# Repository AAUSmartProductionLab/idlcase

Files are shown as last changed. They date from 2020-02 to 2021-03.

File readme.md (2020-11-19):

## Overview

This repository contains everything related to the Industrial data logger suitcase, including Raspberry Pi configuration in `ansible/`, firmware for actual devices (`espBME280/`, `espButton` ... ) and `dash/` which glues a lot of stuff together.

## Concept drawing
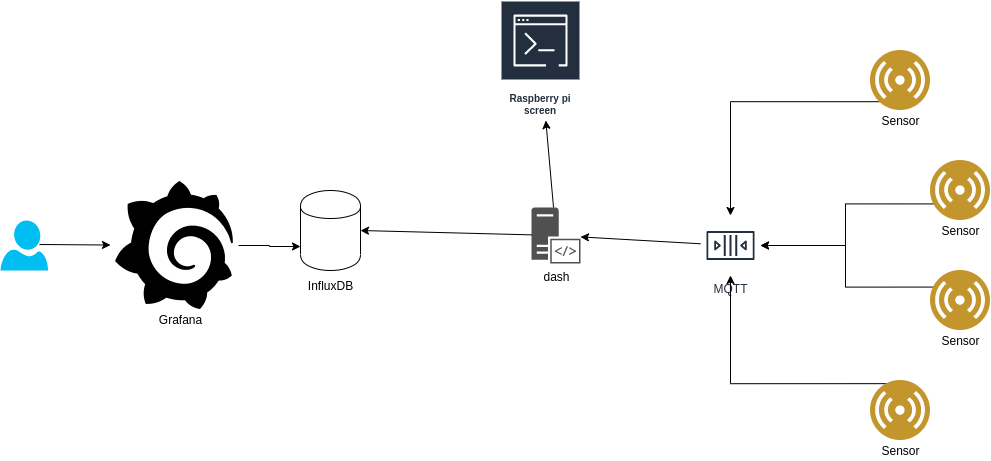
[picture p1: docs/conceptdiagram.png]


Data flows from sensors, though MQTT where `dash` listens for events which it then passes on to the GUI of the Raspberry Pi and stores it in the database.
 
Users access a Grafana frontend where they will be able to browse time series data directly from the database.
All the above software runs locally on the Raspberry Pi

## Connectivity
Raspberry Pi(s) continuously tries to join a VPN with our cloud server - the cloud server acts as a reverse proxy and passes HTTP requests for configured domains directly to the Raspberry Pis inside the VPN. Traffic not inside the VPN and also not directly connected to the Pi's wifi network will be rejected.

## Firmware over-the-air updates
The OTA scheme implemented tries to solve two scenarios
* A developer sits in platformio and wants to update all BME280 sensor devices
* A case is pulled out - some BME280 sensors are updated, some are not - those that are not should be able to update themselves without anyone touching the IDE

To solve these scenarios, the `dash/` projects host simple JSON files describing the latest version of a given firmware type - When a device cold boots, it will try to compare its release to the one fetched from `dash`.

When a developer wants to upload new firmware, `idlversion` and `idluploader` helps figuring out what version number to use next, when running "Upload" it will upload the firmware to the IDL case and publish a message on MQTT which devices listen to. Devices then to the regular OTA update just as if hey where cold booted.

## WifiManager
Our Library IDLNetworking makes use of [tzapu's wifimanager](https://github.com/tzapu/WiFiManager/tree/development). If the ESP device cannot connect to a known wifi it will start the wifimanager. The device will create a hotspot named "CONFIGURE ME - 12AB34" with the ending being the device ID. When connecting to this hotspot all traffic will be routed to a configuration portal that can be accecced with any browser. Connecting from an Android device this portal pops up by itself via a notification. Is that not the case the portal can be accessed on ip address `192.168.1.4`. 
From the portal it is possible to select any nearby access point and type in the password for it. As well as selecting access point it is also possible to set the MQTT server and port to publish on. Finally you can set the server where the ESP-device will check for firmware updates.
Writing `true` into the field named "use defaults below" will set MQTT and firmware server to the ip of gateway.
The protal is kept open for 5 minutes before the device tries to connect to known wifi again.  
Known bugs: wifimanager opens the configuration portal on every other reset. See issue [#1067](https://github.com/tzapu/WiFiManager/issues/1067) for updates. 

## BOM
Raspberry Pi
Raspberry Pi display
4G GSM dongle
esp32 devices and sensors

## MQTT namespaces and Datatypes
Two high-level namespaces exist at the moment, `idl` and `idlota`

### /idl/<deviceID>/<messageType>
Used for incoming events and metrics, `dash` assumes data is metric by default. `<deviceID>`, is used to tag the data and `<messageType` is dictating the format of the json payload. Two message-type formats exists, `events` and `measurements`. Common for both formats is the massages are in an array with an object for each measurement and event. Be aware that the formats does not mix. One array must contain only one format type chosen by the MQTT toppic

**Examples of Metric topics and their payloads:**
```
/idl/C4B3CC/measurements
[
    {       
        "table": "temperature",     // influxdb tabel
        "name": "sensor 1",         // influxdb tag
        "unit": "celcius",          // influxdb tag
        "value": 23.34,             // influxdb value
        "tags":{                    // optional extra tags
            "placement" : "kitchen"
        }
    },
]
```
**Event message**
```
/idl/1C8781/events
[
    {       
        "table": "events",                      // influxdb tabel
        "msg": "someone pushed the red button", // human readable 
        "payload": "{blob}",                    // whatever one sees fit
        "tags": {                               // optional extra tags
            "color":"red",
            "priority": "1",
        }
    },
]
```
**Multiple measurements**
```
/idl/1C8781/measurements
[
    {       
        "table": "temperature",
        "name": "BME280",
        "unit": "celsius",
        "value": 20.5,
    },
    {       
        "table": "microphone",
        "name": "left channel",
        "unit": "dBm",
        "value": 42.47,
        "tags": { 
            "band":"100hz",
        }
    },
    {       
        "table": "microphone",
        "name": "left channel",
        "unit": "dBm",
        "value": 51.25,
        "tags": { 
            "band":"200hz",
        }
    },
    {       
        "table": "microphone",
        "name": "right channel",
        "unit": "dBm",
        "value": 42.87,
        "tags": { 
            "band":"100hz",
        }
    },
    {       
        "table": "microphone",
        "name": "right channel",
        "unit": "dBm",
        "value": 50.15,
        "tags": { 
            "band":"200hz",
        }
    },
]
```

### /idlota topics
These topics are used to announce firmware updates to running devices. There is no payload and publishes to this topic makes sure interested devices check the OTA service for updates.

## Legal
Copyright 2020 Aalborg University
MIT License

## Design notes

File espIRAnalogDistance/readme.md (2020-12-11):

# Analog Infrared Distance Sensor

Handheld device to measure distance to an object. The device consists of the following elements:
  * ESP32
  * Sharp IR sensor  10-80 cm
  * Button
  * Indicator LED
  * Oled screen
  * Piezo speaker

### How to use
Press and hold the button to activate reading mode. When the device is active the indicator led will be on. The device will make a measurement every 250ms and publish a message over MQTT

### Wifi manager
The firmware has a wifimanager that creates a hotspot that when connecting to it you can configure the device via the captive portal. The portal will start automatically if the configured access point is not available.  
In order to force the hotspot and captive portal to start, press and hold the button when turning on the device. The device will beep when the portal opens. 

In order to access the portal connect to the created hotspot named 'CONFIGURE ME - 12AB34'  with the ending being the device ID. When connecting to this hotspot all traffic will be routed to a configuration portal that can be accecced with any browser. Connecting from an Android device this portal pops up by itself via a notification. Is that not the case the portal can be accessed on ip address `192.168.1.4`. 

### MQTT data format
Example of topic and the payload
```
/idl/C4B3CC/measurements
[
    {       
        "table": "distance",        // influxdb table
        "name": "ir_analog",        // influxdb tag
        "unit": "cm",               // influxdb tag
        "value": 23,                // influxdb value
    },
]
```

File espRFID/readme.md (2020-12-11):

# RFID scanner

Handheld device to read mifare-classic RFID tags. The device consists of the following elements:
  * ESP32
  * MFRC522 rfid reader
  * Button
  * Indicator LED
  * Oled screen
  * Piezo speaker

### How to use
Hold the device close to an rfid tag until a beep is heard and the indicator led lights up. The rfid UID is briefly displayed on the oled screen. Press the button to display the UID of the last red tag or press and hold the button when scanning a new tag do display the tag for the duration you hold the button. The UID will be send as an event via MQTT.

### Wifi manager
The firmware has a wifimanager that creates a hotspot that when connecting to it you can configure the device via the captive portal. The portal will start automatically if the configured access point is not available.  
In order to force the hotspot and captive portal to start, press and hold the button when turning on the device. The device will beep when the portal opens. 

In order to access the portal connect to the created hotspot named 'CONFIGURE ME - 12AB34'  with the ending being the device ID. When connecting to this hotspot all traffic will be routed to a configuration portal that can be accecced with any browser. Connecting from an Android device this portal pops up by itself via a notification. Is that not the case the portal can be accessed on ip address `192.168.1.4`. 

### MQTT data format
Example of topic and the payload
```
/idl/1C8781/events
[
    {       
        "table": "events",                             // influxdb table
        "msg": "handheld rfid scan of id:A4 B5 C6",    // human readable version
        "payload": "A4 B5 C6",                         // UID of rfid tag
    },
]
```

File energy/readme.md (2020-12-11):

## maintenance though direct wifi link

If for some reason the energy box cannot be reached from the network, it provides an open ssid which can be used to ssh to it directly so you dont have to pull the box completely apart

You should be able to just connect to it like a regular wifi access point, but heres a cli guide:

```
sudo ip link set wlp6s0 up # where wlp6s0 is your laptops wifi device
sudo iwconfig wlp6s0 essid energy01-direct # again, wlp6so should be your wifi device and energy01-direct is the energy box's ssid
sudo dhclient wlp6s0 # fetch an ip address from the raspberry inside
# or just add an ip address
sudo ip addr add 10.20.30.5/24 dev wlp6s0
```

the raspberry pi should now be accessible on 10.20.30.1

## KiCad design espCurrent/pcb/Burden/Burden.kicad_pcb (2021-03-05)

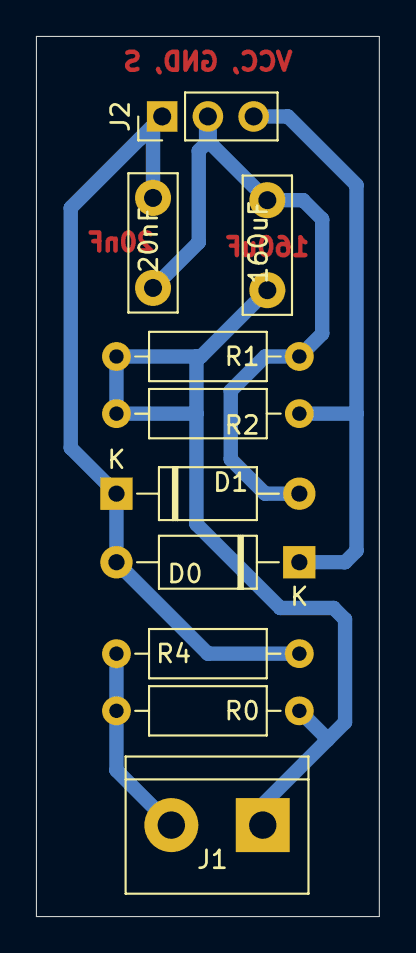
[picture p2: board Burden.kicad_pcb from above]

Board: 2 copper layers, 19.0 x 48.9 mm, 10 parts (0 on the bottom side), 5 nets.

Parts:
20nF, 160uF: C; C_Disc_D7.5mm_W2.5mm_P5.00mm
D0, D1: D; D_A-405_P10.16mm_Horizontal
J1: Screw_Terminal_01x02; TerminalBlock_bornier-2_P5.08mm
J2: Conn_01x03; PinHeader_1x03_P2.54mm_Vertical
R0: R330; R_Axial_DIN0207_L6.3mm_D2.5mm_P10.16mm_Horizontal
R1, R2: R100k; R_Axial_DIN0207_L6.3mm_D2.5mm_P10.16mm_Horizontal
R4: R10K; R_Axial_DIN0207_L6.3mm_D2.5mm_P10.16mm_Horizontal

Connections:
/V_sense: 20nF.2, D0.2, D1.1, J2.1, R4.2
GND: 20nF.1, 160uF.2, D1.2, J2.2, R1.2
unnamed: 160uF.1, J1.1, R0.2, R1.1, R2.2
unnamed: J1.2, R0.1, R4.1
VCC: D0.1, J2.3, R2.1

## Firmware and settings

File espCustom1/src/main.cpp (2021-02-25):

#include <ArduinoJson.h>

#include "version.h"

/***************************************************************************/
// oled screen
#include "SSD1306Wire.h"

/***************************************************************************/
// Industrial Data Logger networking implementation.
#include <IDLNetworking.h>

/***************************************************************************/
// OneWire and DS18B20 libraries
#include <OneWire.h>
#include <DallasTemperature.h>

// Data wire is plugged into port 2 on the Arduino
#define ONE_WIRE_BUS 26
#define TEMPERATURE_PRECISION 11
#define NUMBER_OF_THERMOMETERS 8

/***************************************************************************/
#include <Wire.h>
//#include <Adafruit_Sensor.h>
#include "Adafruit_TSL2591.h"

/***************************************************************************/



/*=========================================================================*/
/*=========================================================================*/
// analog pins

int pins[] = {32,33,34,35};
int nPins = 4;
int analogActivatePin = 12; // pull low to activate analog pins.
int hasAnalogPins = false;

/*=========================================================================*/
// Onewire and DS18B20 sensor instance
OneWire oneWire(ONE_WIRE_BUS); 
DallasTemperature sensors(&oneWire);

int deviceCount = 0;

// Variable to hold temporary device addresses
DeviceAddress thermoAdr;

// Variable to hold temporary temperature values 
float tempC; 

/*=========================================================================*/
// lux sensor instance
TwoWire I2CLight = TwoWire(1);
Adafruit_TSL2591 tsl = Adafruit_TSL2591(2591);
bool hasLuxSensor = false ;

/*=========================================================================*/
// IDLNetworking instance

IDLNetworking idl = IDLNetworking("espCustom1", VERSION);

/*=========================================================================*/
// OLED screen instance
SSD1306Wire display(0x3c, 5, 4);

// display loop
void displayLoop() {
  // Displays device information on the oled dispaly. 
    display.clear();
    if (WiFi.status() != WL_CONNECTED) {
        display.setFont(ArialMT_Plain_24);
        display.drawString(0, 0, idl.getDeviceId());
        display.setFont(ArialMT_Plain_10);
        display.drawString(0, 25, "Connecting...");
        display.drawString(0, 36, idl.getVersionString());
    } else {
        display.setFont(ArialMT_Plain_24);
        display.drawString(0, 0, idl.getDeviceId());
        display.setFont(ArialMT_Plain_10);
        display.drawString(0, 25, WiFi.localIP().toString());
        display.drawString(0, 36, idl.getVersionString());
    }

    display.display();
}


/*=========================================================================*/
// printing a thermometer address as string
void printAddress(DeviceAddress deviceAddress)
{ 
  for (uint8_t i = 0; i < 8; i++)
  {
    Serial.print("0x");
    if (deviceAddress[i] < 0x10) Serial.print("0");
    Serial.print(deviceAddress[i], HEX);
    if (i < 7) Serial.print(", ");
  }
  Serial.println("");
}

/*=========================================================================*/
// Char array printed as string of hex
void array_to_string(byte array[], unsigned int len, char buffer[])
{
    for (unsigned int i = 0; i < len; i++)
    {
        byte nib1 = (array[i] >> 4) & 0x0F;
        byte nib2 = (array[i] >> 0) & 0x0F;
        buffer[i*2+0] = nib1  < 0xA ? '0' + nib1  : 'A' + nib1  - 0xA;
        buffer[i*2+1] = nib2  < 0xA ? '0' + nib2  : 'A' + nib2  - 0xA;
    }
    buffer[len*2] = '\0';
}


/*=========================================================================*/
// struct to hold light data
struct lightData{
    uint16_t full;
    uint16_t ir;
    uint16_t visible;
    float lux;
} myLuxData;

/*=========================================================================*/
// dallas temperature sensors and tls light sensor setup
void sensorsSetup() {
    // temperature sensors
    sensors.begin();

    // locate devices on the bus
    Serial.print("Locating devices...");
    Serial.print("Found ");
    deviceCount = sensors.getDeviceCount();
    Serial.print(deviceCount, DEC);
    Serial.println(" devices.");
    Serial.println("");

    Serial.println("Printing addresses...");
    for (int i = 0; i < deviceCount; i++)    {
        Serial.print("Sensor ");
        Serial.print(i + 1);
        Serial.print(" : ");
        sensors.getAddress(thermoAdr, i);
        printAddress(thermoAdr);

        // set the resolution to x bit per device
        sensors.setResolution(thermoAdr, TEMPERATURE_PRECISION);
    }
    
    // lux sensor
    I2CLight.begin(21,22);
    hasLuxSensor = tsl.begin(&I2CLight);
    
    // You can change the gain on the fly, to adapt to brighter/dimmer light situations
    tsl.setGain(TSL2591_GAIN_LOW);      
 
    // Changing the integration time gives you a longer time over which to sense light
    // longer timelines are slower, but are good in very low light situtations!
    tsl.setTiming(TSL2591_INTEGRATIONTIME_300MS);

    // Print some useful sensor details 
    sensor_t sensor;
    tsl.getSensor(&sensor);
    Serial.println(F("------------------------------------"));
    Serial.print  (F("Sensor:       ")); Serial.println(sensor.name);
    Serial.print  (F("Driver Ver:   ")); Serial.println(sensor.version);
    Serial.print  (F("Unique ID:    ")); Serial.println(sensor.sensor_id);
    Serial.print  (F("Max Value:    ")); Serial.print(sensor.max_value); Serial.println(F(" lux"));
    Serial.print  (F("Min Value:    ")); Serial.print(sensor.min_value); Serial.println(F(" lux"));
    Serial.print  (F("Resolution:   ")); Serial.print(sensor.resolution, 4); Serial.println(F(" lux"));  
    Serial.println(F(""));
    /* Display the gain and integration time for reference sake */  
    Serial.print  (F("Gain:         "));
    tsl2591Gain_t gain = tsl.getGain();
    switch(gain)
    {
        case TSL2591_GAIN_LOW:
        Serial.println(F("1x (Low)"));
        break;
        case TSL2591_GAIN_MED:
        Serial.println(F("25x (Medium)"));
        break;
        case TSL2591_GAIN_HIGH:
        Serial.println(F("428x (High)"));
        break;
        case TSL2591_GAIN_MAX:
        Serial.println(F("9876x (Max)"));
        break;
    }
    Serial.print  (F("Timing:       "));
    Serial.print((tsl.getTiming() + 1) * 100, DEC); 
    Serial.println(F(" ms"));
    Serial.println(F("------------------------------------"));
    Serial.println(F(""));


}

/*=========================================================================*/
// Read IR and Full Spectrum at once and convert to lux
void readLuxSensor()
{
  // More advanced data read example. Read 32 bits with top 16 bits IR, bottom 16 bits full spectrum
  // That way you can do whatever math and comparisons you want!
  uint32_t lum = tsl.getFullLuminosity();
  uint16_t ir, full;
  ir = lum >> 16;
  full = lum & 0xFFFF;
  myLuxData.full = full;
  myLuxData.ir = ir;
  myLuxData.visible = full-ir;
  myLuxData.lux = tsl.calculateLux(full,ir);

//   Serial.print(F("[ ")); Serial.print(millis()); Serial.print(F(" ms ] "));
//   Serial.print(F("IR: ")); Serial.print(ir);  Serial.print(F("  "));
//   Serial.print(F("Full: ")); Serial.print(full); Serial.print(F("  "));
//   Serial.print(F("Visible: ")); Serial.print(full - ir); Serial.print(F("  "));
//   Serial.print(F("Lux: ")); Serial.println(tsl.calculateLux(full, ir), 6);

}

/*=========================================================================*/
// esp setup loop
void setup() {
    Serial.begin(115200);
    delay(100);
    
    // read analog activation pin 
    pinMode(analogActivatePin, INPUT_PULLUP);
    delay(500);
    hasAnalogPins = (0 == digitalRead(analogActivatePin)); // true if activation pin is pulled low
    Serial.print("has analog pins = ");
    Serial.println(hasAnalogPins);

    sensorsSetup();

    idl.begin();

    // Initialising the UI will init the display too.
    display.init();
    displayLoop(); 

    Serial.println("Setup done");
}


/*=========================================================================*/
// esp infinite loop
void loop() {
    idl.loop(2000);
    
    // displayLoop();

    // Send command to all the sensors for temperature conversion
    sensors.requestTemperatures();
    
    // Store temperature from each sensor
    for (int i = 0; i < deviceCount; i++){
        tempC = sensors.getTempCByIndex(i);
        sensors.getAddress(thermoAdr, i);

        char hex_string[20] ;
        array_to_string(thermoAdr, 8, hex_string);

        idl.pushMeasurement("temperature",hex_string,"celsius",tempC);
         
    }

    if(hasLuxSensor ){
        // read light sensor 
        readLuxSensor();
        idl.pushMeasurement("light","sensor 1", "raw_full",myLuxData.full);
        idl.pushMeasurement("light","sensor 1", "raw_ir", myLuxData.ir);
        idl.pushMeasurement("light","sensor 1", "lux", myLuxData.lux);
    }

    if(hasAnalogPins){
        char pin_string[8] ;

        for (int i = 0; i < nPins; i++){
            int adcValue = analogRead(pins[i]);
        
            // NewValue = (((OldValue - OldMin) * (NewMax - NewMin)) / (OldMax - OldMin)) + NewMin.
            float flow = ((adcValue - 182.29) * 15 ) / (3797.78 - 182.29);      
            //min 0.238V = adc 182.29 = 0L/min &&  max 2.975V = adc 3797.78 = 15L/min

            if(flow < 0) flow = 0;

            sprintf(pin_string, "pin:%i", pins[i]);
            idl.pushMeasurement("flow",pin_string, "l/min", flow);
        }
    }

    idl.sendMeasurements();

}

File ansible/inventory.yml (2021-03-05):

all:
  children:
    cloud:
      hosts:
        metric-log01.srv.aau.dk:
          ansible_user: ansible
          ansible_become: yes
          ansible_ssh_common_args: -F ssh_config
          ansible_python_interpreter: /usr/bin/python3
    case:
      hosts:
        10.14.47.2:
          ansible_user: pi
          ansible_become: yes
          ansible_ssh_common_args: -F ssh_config
          ansible_python_interpreter: /usr/bin/python3
          wg0_ip_address: "10.14.47.2"
          hostapd_ssid: idlcase
          hostapd_wpa_password: Aalborg9000Robotlab
        10.14.47.3:
          ansible_user: pi
          ansible_become: yes
          ansible_ssh_common_args: -F ssh_config
          ansible_python_interpreter: /usr/bin/python3
          wg0_ip_address: "10.14.47.3"
          hostapd_ssid: second-case
          hostapd_wpa_password: Aalborg9000Robotlab
        10.14.47.5:
          ansible_user: pi
          ansible_become: yes
          ansible_ssh_common_args: -F ssh_config
          ansible_python_interpreter: /usr/bin/python3
          wg0_ip_address: "10.14.47.5"
          hostapd_ssid: grundfos-case
          hostapd_wpa_password: Aalborg9000Robotlab

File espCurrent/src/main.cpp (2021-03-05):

#include <ArduinoJson.h>

#include "version.h"

/***************************************************************************/
// oled screen
#include "SSD1306Wire.h"
SSD1306Wire display(0x3c, 5, 4);

/***************************************************************************/
// Industrial Data Logger networking implementation.
#include <IDLNetworking.h>
IDLNetworking idl = IDLNetworking("espCurrent", VERSION);

/***************************************************************************/
// EmonLibrary examples openenergymonitor.org, Licence GNU GPL V3
#include "EmonLib.h" // Include Emon Library
EnergyMonitor emon1; // Create an instance

/*=========================================================================*/

// oled display loop
void displayLoop(){
  // Displays device information on the oled dispaly.
  display.clear();
  if (WiFi.status() != WL_CONNECTED){
    display.setFont(ArialMT_Plain_24);
    display.drawString(0, 0, idl.getDeviceId());
    display.setFont(ArialMT_Plain_10);
    display.drawString(0, 25, "Connecting...");
    display.drawString(0, 36, idl.getVersionString());
  }
  else{
    display.setFont(ArialMT_Plain_24);
    display.drawString(0, 0, idl.getDeviceId());
    display.setFont(ArialMT_Plain_10);
    display.drawString(0, 25, WiFi.localIP().toString());
    display.drawString(0, 36, idl.getVersionString());
  }

  display.display();
}

void setup(){
  Serial.begin(115200);

  idl.begin();

  emon1.current(32, 6.06); // Current: input pin, calibration. Amps at 1v ac input

  // Initialising the UI will init the display too.
  display.init();
  displayLoop();

  Serial.println("Setup done");
}

void loop(){
  idl.loop(1000);

  double Irms = emon1.calcIrms(5000); // Calculate Irms only

  Serial.print(Irms * 230.0); // Apparent power
  Serial.print(" ");
  Serial.println(Irms); // Irms

  idl.pushMeasurement("current", "sensor1", "A", Irms);
  idl.pushMeasurement("power", "sensor1", "W", Irms * 230.0);
  idl.sendMeasurements();

}

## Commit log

2020-01-14 Add dash role to case
2020-01-14 Changed inventory with new raspberry ip address
2020-01-14 Add fingerprint to knownhosts
2020-01-20 Dummy IoT Device
2020-01-21 Dash: Its now able to show some sensor data
2020-01-22 Sensor: somewhat working espBME280 sensor
2020-01-22 Changed the deviceID, changed "bs" unit
2020-01-22 dash: Sensor view is now more readable
2020-01-24 dash: Made the Sensor view more human readable
2020-01-27 esp: code for handling buttons and sending events
2020-02-03 In the case of no wifi connection, try to reconnect to wifi before trying to reconnect to MQTT
2020-02-03 esp: fixed reconnect bug
    [main.cpp]
2020-02-05 dash: we are able to serve firmware for devices
2020-02-12 ansible: setup cloud vpn device and network
2020-02-13 ansible: install wireguard to raspberry pi
2020-02-13 ansible: wireguard communication is operational
2020-02-13 ansible: connect to raspberry pies though metric-log01
2020-02-13 ansible: Trust metric-log01's fingerprint
2020-02-17 ansible: added webgateway serving grafana directly from raspberry
2020-02-19 implementing OTA and bugfixes
    [idlNetworking.cpp]
2020-02-19 reset function + bugfix
    [idlNetworking.cpp]
2020-02-19 implementing library. NOT WORKING
    [main.cpp]
2020-02-24 ansible: dont use wvdial and instead relay on simple systemd services
2020-03-04 ansible: create wireguard configuration for clients dynamically
2020-03-23 bugfixes and dithering implementation
    [main.cpp]
2020-03-27 added get device id function
2020-03-27 added dislpay and fixed a buch of comments.
    [main.cpp]
2020-03-30 Added another raspberry pi to ansible
2020-04-06 adding luminosity sensor esp module
2020-06-26 fixed timing issue so it now publises more presice
    [main.cpp]
2020-06-29 bugfixes and minor changes.
    [main.cpp]
2020-07-06 Save point
    [partitions.csv]
2020-07-07 fixes for newest version of espLib
    [main.cpp]
2020-07-08 update devices for new library + bugfixes
    [idlNetworking.cpp, main.cpp]
2020-07-10 renamed and fixed espRFID firmware
    [main.cpp]
2020-08-10 changed to dynamicJsonDocument + timeing fix
    [idlNetworking.cpp]
2020-10-14 New case: added grundfos idl case
2020-10-29 api: current values work in progress
2020-11-10 initialize deviceid and version in constructor
2020-12-11 Energy sensor (#3)
    * energy: users, ntp config and hostapd in master and client mode
    * energy: renamed hostapd role to networking
    * networking: use hardcoded pool of NTP servers
    * networking: ask for ssid and passphrase, docs about maintenance
    * energy: install mbmd
    * energy: various fixes to make it all fit together
    [inventory.yml]
2020-12-11 More readme (#2)
    * fix:spelling mistake
    * add: readme for devices
    * minor changes
    [main.cpp]
2021-01-08 Bugfixes and more (#4)
    * bugfixes for setting defaults
    * bugfix
    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
    [idlNetworking.cpp, main.cpp]
2021-01-08 Analog sense pins (#5)
    * analog sensor pins first commit
    * analog pins done and added
    * fix: commented out upload scirpts
    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
    [main.cpp]
2021-02-25 Esp custom fixes (#10)
    * analog activation pin change, spelling and fixes.
    * new flow calculations
    * change wifiportal timeout
    [idlNetworking.cpp, main.cpp]
2021-03-05 Esp current (#8)
    * pcb for burden resistor and over voltageprotection
    * esp current src
    [Burden.kicad_pcb, Burden.sch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]
2021-03-05 ip update. add keys. minor fixes (#7)
    [inventory.yml]
2021-03-05 pin change and libs (#9)
